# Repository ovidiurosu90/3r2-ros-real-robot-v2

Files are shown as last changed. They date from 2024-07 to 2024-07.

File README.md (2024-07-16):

# [3R2 ROS Real Robot v2](https://github.com/ovidiurosu90/3r2-ros-real-robot-v2)

## Abstract
### Problem
Navigate autonomously without a given map while avoiding obstacles

### Solution
Autonomous Robot Car on ROS

### How
- the whole project is open-source, and can be replicated by interested parties (note it requires a variety of skills like coding, 3d printing, soldering & crimping)
- the robot is able to create a map of an unknown place, then navigate on that map while avoiding obstacles
- SLAM packages on top of ROS are used for navigation

### Notes
- This project was brought to light from my private repository. Some of the resources may be obsolete by now, though feel free to reach out if you need any help
- This project was originally forked from James Bruton's Really Useful Robot (March 2021). His GitHub repository is [here](https://github.com/XRobots/ReallyUsefulRobot "XRobots/ReallyUsefulRobot on GitHub").

## Images

3R2 ROS Real Robot v2 360 rotation

3R2 ROS Real Robot v2 assembly

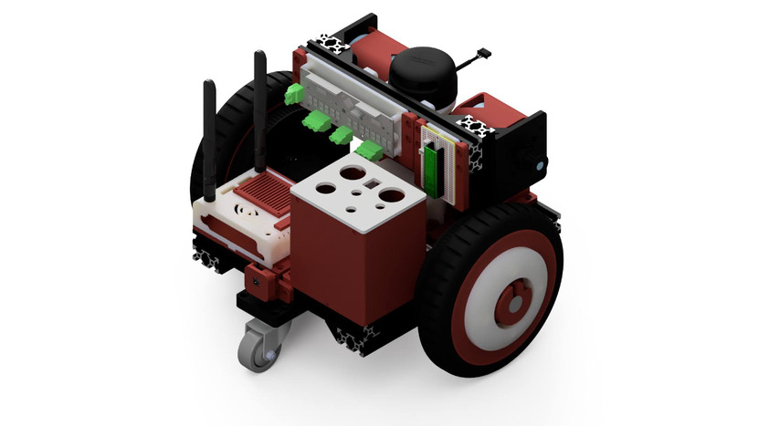
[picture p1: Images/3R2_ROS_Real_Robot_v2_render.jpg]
3R2 ROS Real Robot v2 render


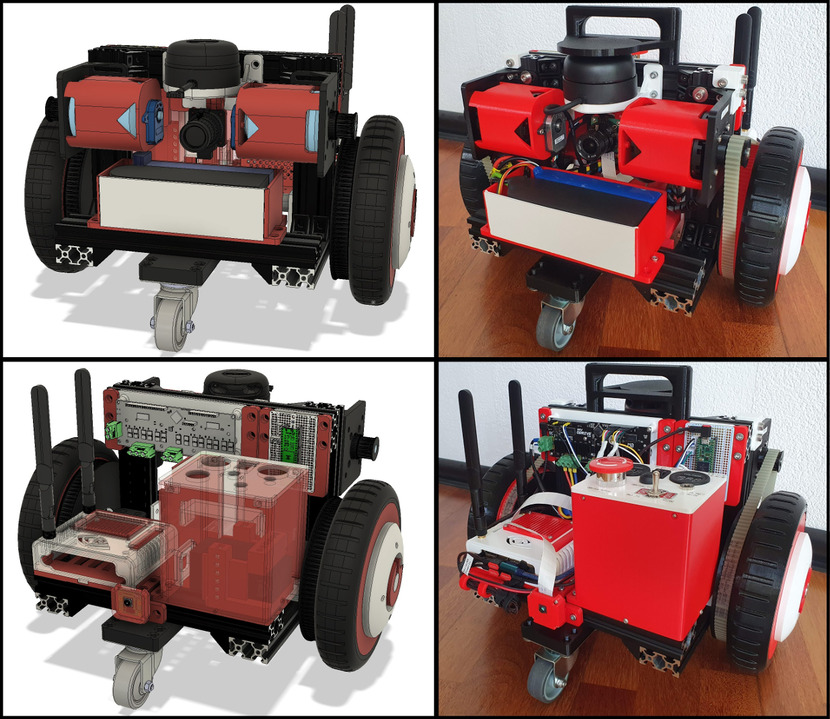
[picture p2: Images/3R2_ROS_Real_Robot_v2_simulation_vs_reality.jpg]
3R2 ROS Real Robot v2 simulation vs reality


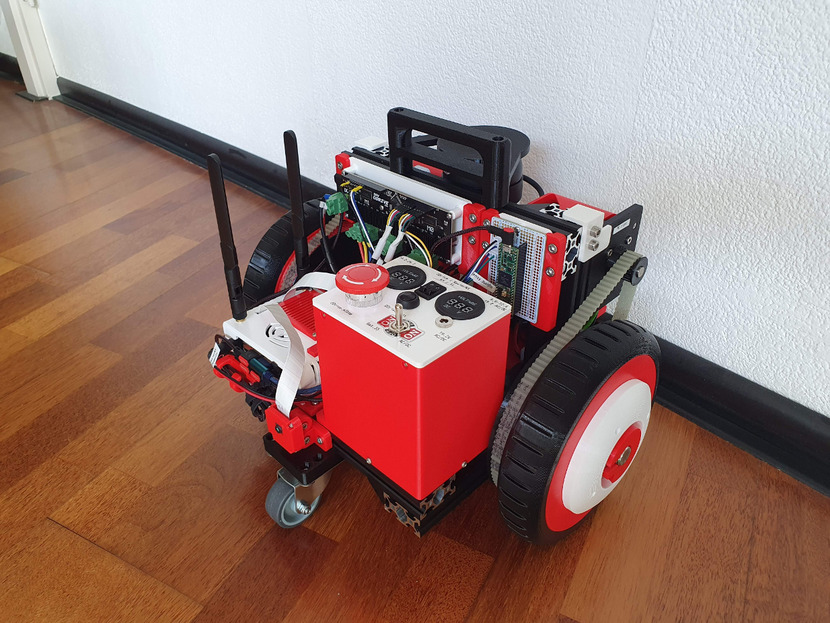
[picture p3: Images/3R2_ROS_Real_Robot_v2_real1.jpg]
3R2 ROS Real Robot v2 real 1


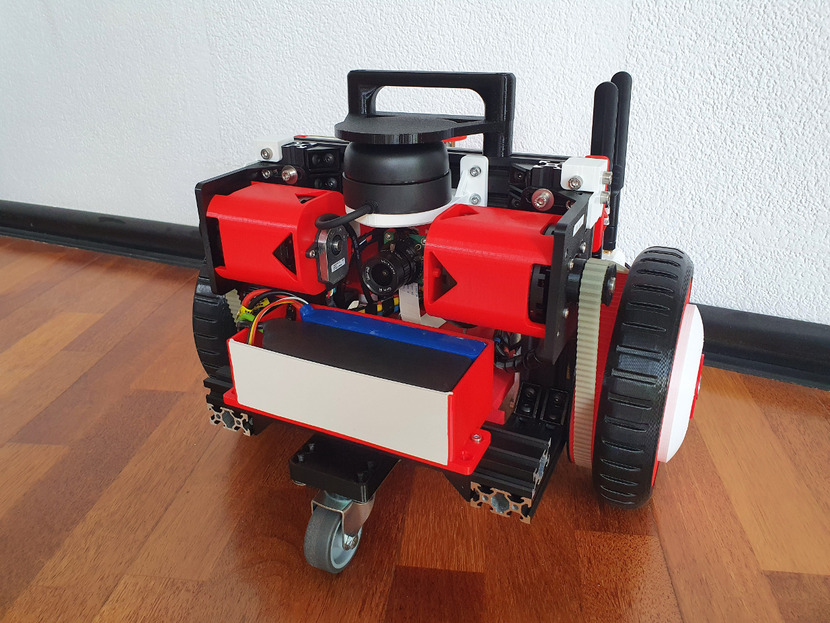
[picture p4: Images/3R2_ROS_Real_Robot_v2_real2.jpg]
3R2 ROS Real Robot v2 real 2


## Getting Started

### Setup 3R2 repository
```bash
mkdir ~/Repositories
cd ~/Repositories/
git clone https://github.com/ovidiurosu90/3r2-ros-real-robot-v2.git
cd 3r2_ros_real_robot_v2/
vim README.md
```

### Install ODrive
```bash
# Install odrivetool: https://docs.odriverobotics.com/#downloading-and-installing-tools
sudo apt-get update
sudo apt-get upgrade
sudo apt install python3 python3-pip
pip3 install matplotlib # optional
pip3 install --upgrade odrive
sudo bash -c "curl https://cdn.odriverobotics.com/files/odrive-udev-rules.rules > /etc/udev/rules.d/91-odrive.rules && udevadm control --reload-rules && udevadm trigger"

vim ~/.bashrc
######
export PATH=$PATH:~/.local/bin
######
source ~/.bashrc
```

### Configure ODrive
```bash
odrivetool
odrv0.erase_configuration() # resets configuration to the factory defaults

odrv0.axis0.controller.config.vel_limit = 16 # default: 2.0
odrv0.axis1.controller.config.vel_limit = 16 # default: 2.0

odrv0.axis0.motor.config.current_lim = 20 # default: 10.0
odrv0.axis1.motor.config.current_lim = 20 # default: 10.0

# Check the calibration current
odrv0.axis0.motor.config.calibration_current # default: 10.0

# Without this setting, I got the ODRIVE_ERROR_DC_BUS_OVER_REGEN_CURRENT error right after the motor stops
odrv0.config.dc_max_negative_current = -8 # default: -0.009999999776482582

# Use encoder index; index = reference point for that encoder to know where to start to count position.
# When the ODrive powers up, the motor will spin until it finds that index
odrv0.axis0.encoder.config.use_index = True # default: False
odrv0.axis1.encoder.config.use_index = True # default: False

odrv0.save_configuration()

# Run full calibration (only once)
odrv0.axis0.requested_state = AXIS_STATE_FULL_CALIBRATION_SEQUENCE
odrv0.axis1.requested_state = AXIS_STATE_FULL_CALIBRATION_SEQUENCE

# Avoid doing the calibration every time the ODrive powers up
odrv0.axis0.encoder.config.pre_calibrated = True # default: False
odrv0.axis1.encoder.config.pre_calibrated = True # default: False

# Look for the index, there's no way around that
# NOTE Make sure there is enough clearance for the motor to move (max 1 turn)
odrv0.axis0.config.startup_encoder_index_search = True # default: False
odrv0.axis1.config.startup_encoder_index_search = True # default: False

# Play the beep sound every time the ODrive powers up
odrv0.axis0.config.startup_motor_calibration = True # default: False
odrv0.axis1.config.startup_motor_calibration = True # default: False

#NOTE You can switch to idle state
# odrv0.axis0.requested_state = AXIS_STATE_IDLE
# odrv0.axis1.requested_state = AXIS_STATE_IDLE

#NOTE You can switch to closed loop state
# odrv0.axis0.requested_state = AXIS_STATE_CLOSED_LOOP_CONTROL
# odrv0.axis1.requested_state = AXIS_STATE_CLOSED_LOOP_CONTROL

#NOTE You can setup the ODrive to enter the closed loop state
# odrv0.axis0.config.startup_closed_loop_control = True # default: False
# odrv0.axis1.config.startup_closed_loop_control = True # default: False

odrv0.save_configuration()
quit
```

### Install PlatformIO
```bash
# Install PlatformIO: https://docs.platformio.org/en/latest//core/installation.html
#NOTE Don't install it in a python virtual environment, as it's causing issues with ROS packages
python3 -m pip install platformio

pio device list

# Setup udev rules for Teensy: https://www.pjrc.com/teensy/00-teensy.rules
sudo vim /etc/udev/rules.d/00-teensy.rules
sudo udevadm control --reload-rules && sudo udevadm trigger
# Unplug Teensy's USB then plug it back
```

### Setup Consistent USB symlinks
```bash
platformio device list
udevadm info -a -n /dev/ttyUSB0 | less
# Copy kernel id for each device (e.g. 1-2.3:1.0)

# JetsonXavierNX
# USB0 | USB2 => 1-2.1:1.0 | 1-2.3:1.0
# USB1 | USB3 => 1-2.2:1.0 | 1-2.4:1.0

sudo vim /etc/udev/rules.d/24-usb.rules
#######################################
SUBSYSTEMS=="usb", KERNELS=="1-2.1:1.0", SYMLINK+="O_ttyUSB0"
SUBSYSTEMS=="usb", KERNELS=="1-2.2:1.0", SYMLINK+="O_ttyUSB1"
SUBSYSTEMS=="usb", KERNELS=="1-2.3:1.0", SYMLINK+="O_ttyUSB2"
SUBSYSTEMS=="usb", KERNELS=="1-2.4:1.0", SYMLINK+="O_ttyUSB3"
#######################################

# USB0 => ODrive
# USB1 => BNO055
# USB2 => RPLidar
# USB3 => Teensy

sudo udevadm control --reload-rules
sudo reboot

# Test that the symlinks are correct
ls -la /dev/O_*
platformio device list
```

### Install ROS

We are using ROS Noetic on Ubuntu 20.04 (dual boot on Desktop) because the XavierNX's OS is based on Ubuntu 20.04 (September 2022)

[Instructions](http://wiki.ros.org/noetic/Installation/Ubuntu)

```bash
lsb_release -a
sudo sh -c 'echo "deb http://packages.ros.org/ros/ubuntu $(lsb_release -sc) main" > /etc/apt/sources.list.d/ros-latest.list'
sudo apt install vim curl
curl -s https://raw.githubusercontent.com/ros/rosdistro/master/ros.asc | sudo apt-key add -
sudo apt update
sudo apt install ros-noetic-desktop-full
apt search ros-noetic
source /opt/ros/noetic/setup.bash
echo "source /opt/ros/noetic/setup.bash" >> ~/.bashrc
source ~/.bashrc
sudo apt install python3-rosdep python3-rosinstall python3-rosinstall-generator python3-wstool build-essential
sudo rosdep init
rosdep update

# vim ~/.ignition/fuel/config.yaml # change url to https://api.ignitionrobotics.org
```

### Setup ROS

[Instructions](http://wiki.ros.org/ROS/Tutorials/catkin/CreateWorkspace)

```bash
mkdir -p ~/catkin_ws/src/
cd ~/catkin_ws/
catkin_make

source devel/setup.bash
echo "source !/catkin_ws/devel/setup.bash" >> ~/.bashrc
source ~/.bashrc

roscd
cd ../src
ln -s ~/Repositories/3r2_ros_real_robot_v2/ROS/geometry2/ .
ln -s ~/Repositories/3r2_ros_real_robot_v2/ROS/jetson_camera/ .
ln -s ~/Repositories/3r2_ros_real_robot_v2/ROS/ros_imu_bno055/ .
ln -s ~/Repositories/3r2_ros_real_robot_v2/ROS/ros_real_robot_v2/ .
ln -s ~/Repositories/3r2_ros_real_robot_v2/ROS/ros_real_robot_v2_simulations/ .
ln -s ~/Repositories/3r2_ros_real_robot_v2/ROS/rosserial/ .
ln -s ~/Repositories/3r2_ros_real_robot_v2/ROS/rplidar_ros/ .

cd ..
rm -rf build/ .catkin_workspace devel/
catkin_make
source ~/.bashrc
rospack profile

sudo ln -s /usr/include/opencv4/opencv2/ /usr/include/opencv

sudo apt-get install ros-noetic-teleop-twist-keyboard ros-noetic-rosbash ros-noetic-xacro ros-noetic-joint-state-publisher-gui ros-noetic-gmapping ros-noetic-slam-gmapping ros-noetic-map-server ros-noetic-navigation ros-noetic-ros-tutorials ros-noetic-compressed-image-transport ros-noetic-camera-info-manager ros-noetic-rviz-imu-plugin ros-noetic-robot-localization ros-noetic-rosserial-arduino

rosdep update
rosdep install --from-paths . --ignore-src

sudo apt install python3-pip
pip3 install pyyaml rospkg pyserial

#NOTE Only for XavierNX
sudo chmod 777 /dev/O_ttyUSB2 # RPLidar
sudo adduser [USERNAME] dialout
sudo reboot
```

### Run ROS
```bash
# Press small pushbutton to initialise the ODrive

# Run the following in different terminals on the SBC (NVIDIA Jetson Xavier NX)

roscore

roslaunch ros_real_robot_v2_bringup robot.launch

# rosrun teleop_twist_keyboard teleop_twist_keyboard.py
rosrun ros_real_robot_v2_teleop ros_real_robot_v2_teleop_key

rostopic echo /tf

rostopic echo /odom
    # twist.twist.linear.x should be similar to speed in teleop
    # twist.twist.angular.x & y could be used for debugging the pos0 and pos1 from ODrive
    #     (NOTE Check the code on the MainControllerTeensy)
```

### Upload the firmware on the Main Controller (Teensy 4.1)
```bash
cd ~/Repositories/3r2_ros_real_robot_v2/Arduino/MainControllerTeensy/
vim src/main.cpp
pio run --target upload
```

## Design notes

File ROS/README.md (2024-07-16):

# **ROS Setup**

## TODO [Tune ROS navigation parameters](https://kaiyuzheng.me/documents/navguide.pdf)

## Simulations

### Simple test in empty world
```bash
roslaunch ros_real_robot_v2_gazebo empty_world.launch
roslaunch ros_real_robot_v2_bringup model.launch

# rosrun teleop_twist_keyboard teleop_twist_keyboard.py
rosrun ros_real_robot_v2_teleop ros_real_robot_v2_teleop_key
```

### Creating a map with gmapping
```bash
roslaunch ros_real_robot_v2_gazebo turtlebot3_house.launch
roslaunch ros_real_robot_v2_slam slam.launch

rosrun ros_real_robot_v2_teleop ros_real_robot_v2_teleop_key

roscd ros_real_robot_v2_navigation/maps/
rosrun map_server map_saver -f turtlebot3_house
```

### Navigating on a known map
```bash
roslaunch ros_real_robot_v2_gazebo turtlebot3_house.launch
roslaunch ros_real_robot_v2_navigation navigation.launch map_file:=$(rospack find ros_real_robot_v2_navigation)/maps/turtlebot3_house.yaml

# Rotate until the number of particles is small and they are under or close to the robot
# After the pose estimate is okay, close this node, otherwise it will conflict with the nevigation stack
rosrun ros_real_robot_v2_teleop ros_real_robot_v2_teleop_key
```

#### Note known error with roswtf

While runing the navigation stack, roswtf shows the following error:

```bash
roswtf

ERROR The following nodes should be connected but aren't:
 * /move_base->/move_base (/move_base/global_costmap/footprint)
 * /move_base->/move_base (/move_base/local_costmap/footprint)
```

You can ignore it as it is being shown while running the navigation stack on turtlebot3 as well.

`rqt_graph` && `rosrun rqt_tf_tree rqt_tf_tree` are showing similar results with turtlebot3 in simulation.

## Real World

### Known IPs
- XavierNX:    192.168.50.108
- Desktop:     192.168.50.136
- Leptop:      192.168.50.198

### Network Test

```bash
# On Ubuntu (0)
export ROS_HOSTNAME=192.168.50.136
export ROS_MASTER_URI=http://192.168.50.136:11311
export ROS_IP=192.168.50.136
roscore

# On XavierNX (0)
export ROS_MASTER_URI=http://192.168.50.136:11311
export ROS_IP=192.168.50.108
rosrun rospy_tutorials listener.py

# On Ubuntu (1)
export ROS_HOSTNAME=192.168.50.136
export ROS_MASTER_URI=http://192.168.50.136:11311
export ROS_IP=192.168.50.136
rosrun rospy_tutorials talker.py

# You should see data being sent between two nodes
```

### Network Setup
```bash
# On Ubuntu (0)
vim ~/.bashrc
#########################
source /opt/ros/noetic/setup.bash
source ~/catkin_ws/devel/setup.bash
export ROS_HOSTNAME=192.168.50.136
export ROS_MASTER_URI=http://192.168.50.136:11311
export ROS_IP=192.168.50.136
#########################
source ~/.bashrc

# On XavierNX (0)
vim ~/.bashrc
#########################
source /opt/ros/noetic/setup.bash
source ~/catkin_ws/devel/setup.bash
export ROS_MASTER_URI=http://192.168.50.136:11311
export ROS_IP=192.168.50.108
#########################
source ~/.bashrc
```

### Building the map
```bash
# On Ubuntu (0)
roscore

# On XavierNX (0)
roslaunch ros_real_robot_v2_bringup robot.launch

# On Ubuntu (1)
roslaunch ros_real_robot_v2_slam slam.launch

# On Ubuntu (2)
rosrun ros_real_robot_v2_teleop ros_real_robot_v2_teleop_key
# Move around until the map is complete

# On Ubuntu (3)
roscd ros_real_robot_v2_navigation/maps/
rosrun map_server map_saver -f apartment1
```

## Navigate the known map
```bash
# On Ubuntu (0)
roscore

# On XavierNX (0)
roslaunch ros_real_robot_v2_bringup robot.launch

# On Ubuntu (1)
roslaunch ros_real_robot_v2_navigation navigation.launch
# roslaunch ros_real_robot_v2_navigation navigation.launch map_file:=/home/[USERNAME]/catkin_ws/src/ros_real_robot_v2/ros_real_robot_v2_navigation/maps/apartment1.yaml

# On Ubuntu (2): Check if everything is fine
cd ~/Desktop/
rosrun tf view_frames && evince frames.pdf
```

# Adafruit BNO055 IMU

## View IMU

```bash
# On Ubuntu (0)
roscore

# On XavierNX (0)
# roslaunch ros_real_robot_v2_bringup imu.launch # IMU operation_mode
# roslaunch ros_real_robot_v2_bringup imu.launch operation_mode:=NDOF_FMC_OFF
roslaunch ros_real_robot_v2_bringup imu.launch operation_mode:=NDOF

# On Ubuntu (1)
roslaunch ros_real_robot_v2_utils view_imu.launch

# On XavierNX (1)
rosservice call /imu/reset_device "{}" # Reset orientation of the axis perpendicular to the ground plane
rosservice call /imu/calibration_status "{}"
```

## Calibration IMU

```bash
# On Ubuntu (0)
roscore

# On XavierNX (0)
roscd ros_imu_bno055/src # this is where the calibration files will be stored
# rm IMU_calibration NDOF_FMC_OFF_calibration
roslaunch ros_imu_bno055 imu_calibration.launch serial_port:=/dev/O_ttyUSB1 operation_mode:=IMU
roslaunch ros_imu_bno055 imu_calibration.launch serial_port:=/dev/O_ttyUSB1 operation_mode:=NDOF_FMC_OFF
roslaunch ros_imu_bno055 imu_calibration.launch serial_port:=/dev/O_ttyUSB1 operation_mode:=NDOF
```

## Sensor Fusion

```bash
# On Ubuntu (0)
roscore

# On XavierNX (0)
roslaunch ros_real_robot_v2_bringup robot.launch

# On Ubuntu (1)
roslaunch ros_real_robot_v2_bringup model.launch
# Add rviz_imu_plugin (Create visualization by display type), select topic /imu/data, enable box

# On Ubuntu (2)
rosrun ros_real_robot_v2_teleop ros_real_robot_v2_teleop_key
```

# Run tests

## cmd_vel_odom_test0 in simulation (Feb 05, 2022)
```bash
roslaunch ros_real_robot_v2_gazebo empty_world.launch
roslaunch ros_real_robot_v2_bringup model.launch
rosrun ros_real_robot_v2_utils cmd_vel_odom_test0.py

# Results (3 tries, ~200 odom msgs): linearError% between(-0.23, 1.55) and angularError% between(1.30, 3.13)
```

## cmd_vel_odom_test0 in the real world (Feb 05, 2022)
```bash
# On Ubuntu (0)
roscore

# On XavierNX (0)
roslaunch ros_real_robot_v2_bringup robot.launch

# On Ubuntu (1)
roslaunch ros_real_robot_v2_bringup model.launch

# On Ubuntu (2)
rosrun ros_real_robot_v2_utils cmd_vel_odom_test0.py

# Results (4 tries, ~360 odom msgs): linearError% between(-9.55, -10.12) and angularError% between(-9.93, -10.23)
```

## cmd_vel_odom_test0 in the real world (Feb 12, 2022)
```bash
# The commands are the same as above

# Results (3 tries, ~200 odom msgs): linearError% between(-0.19, 0.26) and angularError% between(-0.09, 0.11)
# The inconsistency is now fixed.
# The error was that the code was trying to maintain a transfer rate of 100Hz but it wasnâ€™t able to.
# The calculations were implying that, which was wrong. Using the correct cycle time (instead of the inferred one) fixed the issue.
```

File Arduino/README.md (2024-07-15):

# Arduino
Programming the microcontroller was done using [PlatformIO](https://platformio.org/) - Arduino framework.

TODO Before uploading the firmware to the microcrontroller, we have to set a few configuration parameters.

I use a custom made script that bundles a few of the PlatformIO together, though in short, these are the steps to be run to program the microcontroller:
```bash
platformio pkg update
platformio run
platformio run --target upload
platformio device monitor --port /dev/O_ttyUSB0 --baud 115200 | ts [%Y-%m-%d %H:%M:%S] | tee -a MainControllerTeensy.log
```

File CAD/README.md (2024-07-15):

# CAD
I am using Autodesk Fusion 360 as the main CAD software.
In this folder you can find the .f3z file, which contains all the .f3d Fusion 360 3D design files. I chose to upload the f3z file instead of a bundle of STEP files as it holds the complete design and it's way easier to update.

NOTE Install Autodesk Fusion 360, then import everything by following the steps:

1. create a new project by clicking ‘New Project’ in the left toolbar
1. open the new project by double clicking its name
1. upload the .f3d archive from GitHub ([CAD](CAD)) by clicking ‘Upload’ in the left toolbar
1. wait a few minutes, this is uploading multiple designs to your Fusion 360 project
1. open the main assembly (3R2 ROS Real Robot v2 September 2022) by double clicking its name. It should look something like this

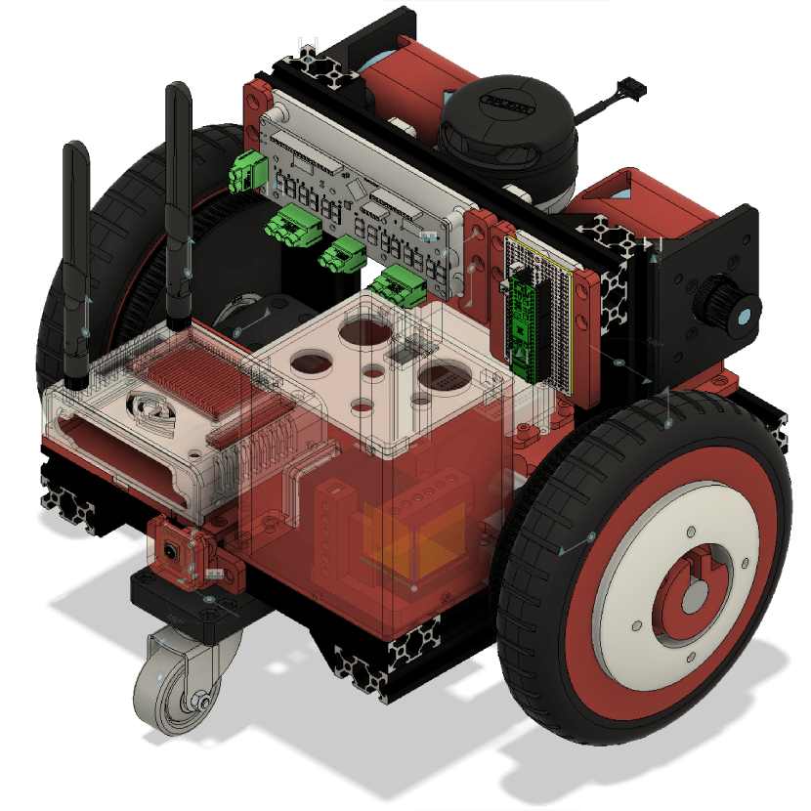
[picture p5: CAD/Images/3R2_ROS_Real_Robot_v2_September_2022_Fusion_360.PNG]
3R2 ROS Real Robot v2 September 2022 in Fusion 360


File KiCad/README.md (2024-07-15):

# KiCad
I am using KiCad 8.0 as the main electronics design software. The project at the moment has no custom PCBs, though you can find an overall connection diagram (between different components) that was designed with this tool.

## TODO Images

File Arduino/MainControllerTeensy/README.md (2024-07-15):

[//]: # (Some of the lines end with 2 spaces. This is the way to specify a line break in markdown)

# Wheel Reduction

ODrive updated their firmware and starting with v0.5.1 **'encounter counts' changed to 'turns'**. For more info check ODrive's [Migration Guide](https://docs.odriverobotics.com/migration).

In the original release from James Bruton (commit on Nov 3, 2020), the encoder units were encoder counts. Now we use turns.

## Hardware

We use ODrive's [CUI AMT102](https://eu.odriverobotics.com/shop/cui-amt-102) capacitive encoders, which have 8192 counts per resolution.

The motor pulleys have 15 teeth. The wheel pulleys have 96 teeth.  
96/15 = 6.4 => 15:96 reduction == **6.4:1** reduction

The wheels have 200mm in diameter. Circumference C = 2 * PI * radius.  
C = 2 * 3.141592 * 100 => **628.318530** mm calculated circumference (approximated by James at 628.32; 633 in reality).

The distance between wheels is **346** mm in the 3d model (353 mm in reality).

## Driving Forward

1 revolution of the wheel means 628.318530 mm (approximated by James at 628.32) travelled.

The motor needs to turn 6.4 times to make a full revolution (because of the 6.4:1 reduction).

1 wheel revolution = 6.4 motor turns = 6.4 * 8192 encoder counts = 52428.8 encoder counts (approximated by James at 52428).

1 wheel revolution = 628.318530 mm => for each travelled mm we have 52428.8 / 628.318530 encoder counts.  
52428.8 / 628.318530 = 83.443026 encoder counts per mm (approximated by James to 83.44, value in his code)

6.4 motor turns / 628.318530 mm = **0.010185** turns per mm (value in my code based on 3d model measurements)

### Calculate the number of encoder counts / turns we need in order to travel at 1 meter per second

1 revolution ... 628.318530 mm  
x revolution ... 1000 mm (1m)  
x = 1 * 1000 / 628.318530 = 1.591549 revolutions per m (approximated by James to 1.592)

1.591549 revolutions per m * 52428.8 encoder counts = 83443.004211 encoder counts per m  
1.591549 revolutions per m * 6.4 turns = 10.185913 turns per m

each meter / sec = 83443.004211 encoder counts (approximated by James to 83466, value in his code)  
each meter / sec = **10.185916** turns (value in my code based on 3d model measurements)

## Turning

360 degrees = 2 * PI radians  
180 degress = PI radians

### Distance each wheel has to travel in order to turn 180 degrees

346 mm (distance between wheels) * PI / 2 (number of wheels)  
= 346 * 3.141592 / 2 = 543.495416 mm (approximated by James to 565.48 mm)

1 revolution ... 628.318530 mm  
x revolution ... 543.495416 mm  
x = 1 * 543.495416 / 628.318530 = 0.864999 revolutions

0.864999 revolutions * 6.4 motor turns = 5.535998 motor turns (NOTE James has 5.78 here)  
5.535998 * 8192 = 45350.902616 encoder counts (approximated by James to 47411)

1 radian = 45350.902616 / PI = 14435.643653 encoder counts (approximated by James to 15091, value in his code)  
1 radian = 5.535998 / PI = **1.762163** turns (value in my code based on 3d model measurements)

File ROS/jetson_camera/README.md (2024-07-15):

# Jetson CSI camera node(let)

Forked from [sfalexrog' jetson_camera](https://github.com/sfalexrog/jetson_camera). I've changed the OpenCV version from 3 to 4, I've added sensor_id and camera_name.

The node(let) is based on the [JetsonHacks' Jetson Nano CSI repository](https://github.com/JetsonHacksNano/CSI-Camera). As such, it only supports Raspberry Pi v2 cameras (and others that are supported by Jetson Nano). Additionally, it requires OpenCV with GStreamer support (see [JetsonHacks' OpenCV build scripts](https://github.com/JetsonHacksNano/buildOpenCV) to build one).

## Parameters

* `cap_width`, `cap_height` (*int*, default: 1280, 720) - Width and height of the captured image. **These parameters only affect the capturing mode!** Be sure to set them to one of the supported modes for your camera (Raspberry Pi camera v2 supports 3280x2464@21fps, 3280x1848@28fps, 1920x1080@30fps, 1280x720@60fps).
* `width`, `height` (*int*, default: 640, 480) - Width and height of the output image.
* `fps` (*int*, default: 60) - Desired framerate/publish rate [Hz].
* `flip_method` (*int*, default 0) - Image rotation/flipping. `0` for no rotation, see detailed description [at JetsonHacks](https://github.com/JetsonHacksNano/CSI-Camera#gstreamer-parameter).
* `frame_id` (*string*, default: "main_camera_optical")- Camera frame name.
* `capture_delay` (*double*, default: 0) - Additional time (in seconds) that is **substracted** from the timestamp. Allows to compensate for capture delays.
* `topic_name` (*string*, default: "image_raw") - Image topic name.
* `camera_info_url` (*string*, default: "") - URL pointing to the camera info yaml file.

## Nodelet

The node is meant to run as a nodelet (`jetson_camera/JetsonCameraNodelet`). In fact, the node is basically a standalone simplified nodelet manager.

## Miscellaneous stuff

### Red tint on camera image

The image captured by this node may have a red tint that is more pronounced near the edges. This can be fixed to a degree by using an ISP camera override.

An ISP override file for an Arducam imx219 board (`camera_overrides.isp`) is placed in this repository in the `extra` folder. Place it in the `/var/nvidia/nvcam/settings` on your Jetson Nano, set its permissions to `664` and its owner:group to `root:root`.

Note that, [according to RidgeRunner](https://developer.ridgerun.com/wiki/index.php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), only ODMs have access to the required tools for ISP calibration files.

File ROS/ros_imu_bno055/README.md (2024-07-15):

# ros_imu_bno055

Forked from [RoboticArts'  ros_imu_bno055](https://github.com/RoboticArts/ros_imu_bno055). I didn't make any changes.

**Author**: Robert Vasquez Zavaleta

*Robotic Arts, All Rights Reserved 2020*

Software License Agreement (BSD License)

**Description**: ROS driver for the BNO055 IMU using serial communication. Also it allows the configuration and calibration of the IMU

## Overview

BNO055 IMU is a Bosh sensor that  integrates an accelerometer, a gyroscope and a magnetometer in one package. Unlike other IMUs, the BNO055 is able to directly offer orientation in space. This is thanks to the different sensory fusion algorithms implemented on the chip. In this way, it is not necessary to perform additional calculations. Also, it is capable of using I2C or UART communication.

**This repository offers a ROS package** and an API written in python to **communicate with the IMU BNO055 using UART** communication through a USB Serial Converter. In addition, all the necessary functionalities have been **implemented** to correctly use the **sensor calibration**. On the other hand, thanks to the API it **is possible to set** various **configuration parameters** of the IMU.

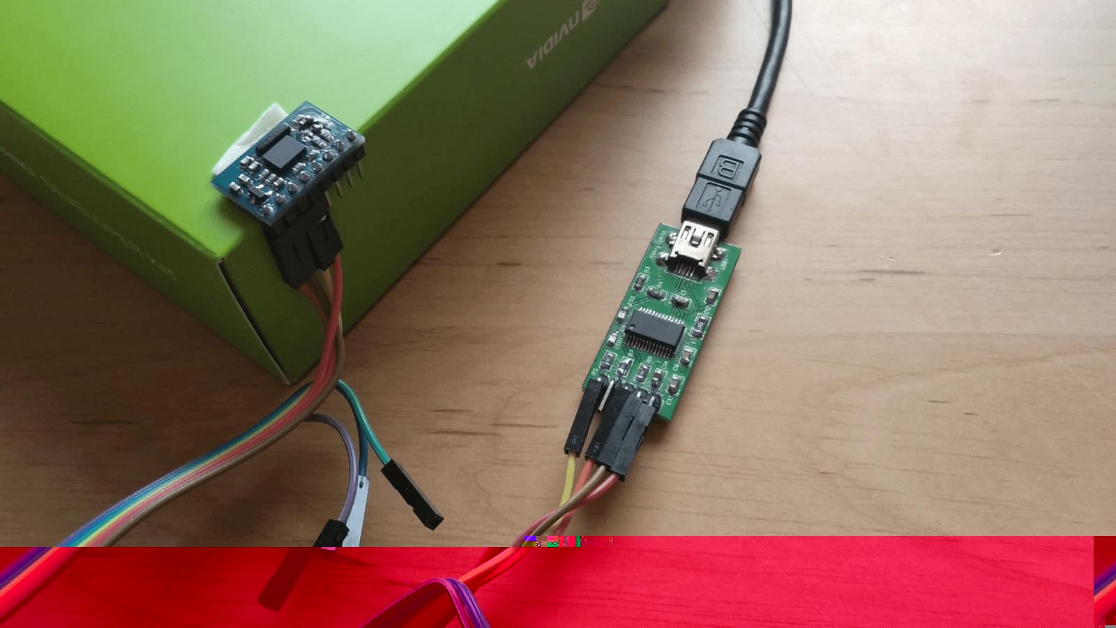
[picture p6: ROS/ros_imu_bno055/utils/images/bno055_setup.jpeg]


## 1. Requisites

* Ubuntu with ROS Kinetic or Melodic
* Python 3
* Bosch IMU BNO055
* USB Serial Converter

## 2. Hardware setup

There are different boards that incorporate the BNO055 IMU. The cheapest one is from Aliexpress. This board has two solder bridges called PS0 and PS1 used to select the type of communication. 

On the other hand, on this board the solder bridges are inverted. This means that its state is 1 if the bridge is not soldered. If the bridge is soldered the state is 0. The table on the left, obtained from the BNO055 datasheet, shows the communication modes based on PS0 and PS1

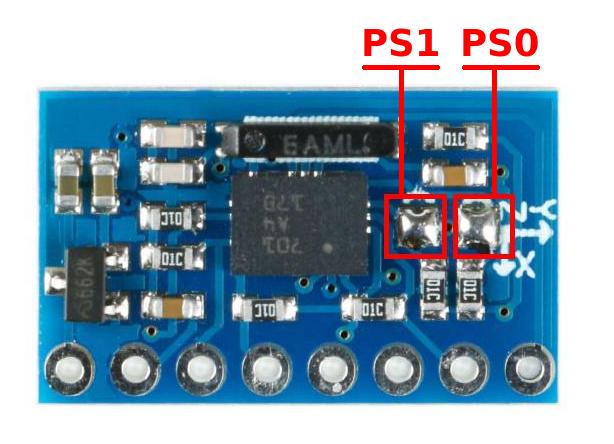
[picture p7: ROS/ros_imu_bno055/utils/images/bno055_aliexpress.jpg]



**To use the IMU in this package**, it must be configured in **UART mode** to be able to communicate with the serial to USB converter. Therefore PS0 = 0 and PS1 = 1. Remember that on this board the solder bridges are inverted, so the PS1 bridge must be unsolder.

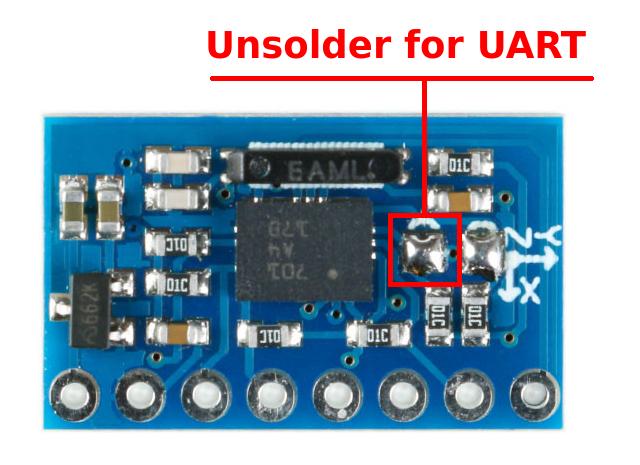
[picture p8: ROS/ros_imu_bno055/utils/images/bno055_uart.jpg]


Finally, connect the IMU to the serial to USB converter. The Rx and Tx cables are crossed. The power of the BNO055 module is 5V



If you are using a different board, for example the Adafruit board or a different Chinese board, use [this link](https://gr33nonline.wordpress.com/2019/04/19/dont-get-the-wrong-bno055/)

## 3. Dependences

ros_imu_bno055 package depends on the following python/ros packages:

* pyserial
* rviz_imu_plugin

## 4. Installation

Install ros_imu_bno055 package

```
$ cd ~/catkin_ws/src
$ git clone https://github.com/RoboticArts/ros_imu_bno055.git
```

It is important to compile the package so that the libraries are added correctly

```
$ cd ~/catkin_ws
$ catkin_make --only-pkg-with-deps ros_imu_bno055
$ source devel/setup.bash
```

By default the standard ROS installation does not include any plugin to display the orientation of the IMUs in rviz. Therefore, you will need to install the **Imu plugin**. If you does not need to see the IMU in rviz you can skip this step.

Kinetic:
```
$ sudo apt-get install ros-kinetic-rviz-imu-plugin
```
Melodic:
```
$ sudo apt-get install ros-melodic-rviz-imu-plugin
```

Finally pyserial must be installed if it is not on the computer. 

```
$ pip install pyserial
```

(Optional) If you are using a Serial to USB converter with the **original FTDI chip** you can install the udev rule to identify the device as ```ttyUSB_IMU```

```
$ roscd ros_imu_bno055
$ sudo cp utils/99-bno055.rules /etc/udev/rules.
$ sudo udevadm control --reload-rules && sudo udevadm trigger
```

## 5. View IMU

1. Make sure to connect the IMU well to the computer. Check the Hardware Setup section for more information

2. In a terminal, launch the following command to display the IMU in RVIZ

```
$ roslaunch ros_imu_bno055 view_imu.launch
```

3. Move the IMU to view its orientation in RVIZ.



## 6. BNO055 ROS driver

1. Use the command below to start the driver in ROS. This launch file is the same as the previous one but neither the tf nor rviz is published

```
$ roslaunch ros_imu_bno055 imu.launch serial_port:=/dev/ttyUSB0
```

2. This driver allows to configure various parameters of the IMU. The following table describes each parameter

| Argument | Default value | Description |
| --- | --- | --- |
| serial_port | /dev/ttyUSB0 | USB port where the IMU is connected (using a USB Serial Converter ) |
| frame_id | imu_link | Name of the link that the tf will use |
| operation_mode | IMU |  Type of sensory fusion used by the IMU. The next section will explain each mode in detail. |
| oscillator | INTERNAL | Use internal or external oscillator. Set EXTERNAL if you BNO055 board has a external oscillator to get more accurate clock vary for lower sensitivity error (this does not improve drift).
| reset_orientation | true | Resets the IMU to resets the orientation of the axis that is located perpendicular to the ground plane. This is important since the movements are relative to the first position the IMU had when it was turned on or reset. Set it to True to reset the position every time the driver is launched|
| frequency | 50 | Frequency of reading the IMU and publication in ROS. The maximum frequency reached by the IMU is 50 Hz |
| use_magnetometer | false | Enables topic imu/magnetometer |
| use_temperature | false | Enables topic imu/temperature |

3. The IMU BNO055 implements a sensory fusion algorithm based on the accelerometer, gyroscope and magnetometer to obtain orientation. These sensory fusion modes are:

| Operation mode | Description |
| --- | --- |
| IMU | The relative orientation of the BNO055 in space is calculated from the accelerometer and gyroscope data. |
| COMPASS | This mode is intended to measure the magnetic earth field and calculate the geographic direction. The heading  can only be calculated when considering gravity and magnetic field at the same time  |
| M4G | Similar to the IMU mode, but instead of using the gyroscope signal to detect rotation, the changing orientation of the magnetometer in the magnetic field is used. |
| NDOF_FMC_OFF | This fusion mode is same as NDOF mode, but with the Fast Magnetometer Calibration turned ‘OFF’.  |
| NDOF | The absolute orientation data is calculated from accelerometer, gyroscope and the magnetometer.  In this mode the Fast Magnetometer calibration is  turned  ON  and  thereby  resulting  in  quick  calibration  of  the  magnetometer |

4. When selecting an operating mode, the sensors involved and the resulting type of orientation must be taken into account. The table below shows the possible combinations.

**Note: Sensors not used in one mode of operation will turn off.** For example, if the IMU mode is selected, the magnetometer will not work and therefore its value cannot be published in ROS. Also keep in mind that its orientation will be relative.

| Operation mode | Accelerometer | Gyroscope | Magnetometer | Orientation |
| --- | :---: | :---: | :---: | :---: |
| IMU | X | X |  | Relative |
| COMPASS | X |  | X | Absolute |
| M4G | X |  | X | Relative |
| NDOF_FMC_OFF | X | X | X | Absolute |
| NDOF | X | X | X | Absolute |

**5. Reset device service**

When IMU is reset it is possible to reset the orientation of the IMU while the driver is running. **Only the orientation of the axis that is perpendicular to the ground plane will be reset**. To do this, call the service below. After calling the service the IMU will be reset and therefore the initial orientation will be the orientation that it has at that moment.

```
$ rosservice call /imu/reset_device "{}"
```

**6. Calibration status service**

Returns the current state of the calibration. This service should not be called constantly since it stops the publication of the IMU:

```
$ rosservice call /imu/calibration_status "{}"
```

**7. Calibration load**

Every time the driver is launched automatically it will look for the calibration file called ```calibration```. If found, it will load the calibration into the IMU. If not found it will not load it and the IMU will use the internal factory calibration. This file is in the following path:

```
$ roscd ros_imu_bno055/src
```

The file ```calibration``` is a binary file generated by the ```imu_calibration``` node. See the next section to find out how to use that node.

**Every time the IMU is turned on or reset, the calibration must be loaded since the IMU does not have an EEPROM or flash memory.** This driver takes care of it.

8. If you are going to implement it in a launch file:

```
    <include file="$(find imu_ros_bno055)/launch/imu.launch">

        <arg name = "serial_port" value="/dev/ttyUSB0" />
        <arg name = "frame_id" value="imu_link" />
        <arg name = "operation_mode" value="IMU"/>
        <arg name = "oscillator" value="INTERNAL" />
        <arg name = "reset_orientation" value="true" />
        <arg name = "frequency" value="50" /> 
        <arg name = "use_magnetometer" value="false" />
        <arg name = "use_temperature" value="false" /> 

    <launch>
```

9. If you are going to throw it in the terminal:

```
roslaunch ros_imu_bno055 imu.launch serial_port:=/dev/ttyUSB0 operation_mode:=IMU
```

## 7. IMU calibration

BNO055 IMU has an internal factory calibration, however, it is highly recommended to calibrate it. The node ```imu_calibration``` generates a calibration file for the accelerometer, gyroscope, and magnetometer. The generated file will be used by the bno055 ros driver to load it into the IMU. Remember that BNO055 does not have an EEPROM or flash memory to store the calibration so every time the IMU is turned on or reset, the calibration has to be loaded.

**The type of calibration obtained** will **depend on the operating mode** of the IMU (see table in section 6.3). This means that if the IMU will work in NDOF_FMC_OFF mode then the calibration has to be done in that same mode.

To launch the calibration, in this case operation mode will be ```NDOF_FMC_OFF```:

```
roslaunch ros_imu_bno055 imu_calibration.launch serial_port:=/dev/ttyUSB0 operation_mode:=NDOF_FMC_OFF
```

The status of the three sensors will immediately appear on the terminal. Value 0 means there is no calibration, value 3 means full calibration. The parameter ```system```  indicates the current status of the three sensors. A value of 0 indicates that there is no calibration. A value of 3 indicates that the IMU has completed the calibration



* **To calibrate the magnetometer:** Make  some random movements  (for  example:  writing  the  number  ‘8’  on air) until  the magnetometer indicates fully calibrated

* **To calibrate the gyroscope:** Place the device in a single stable position for a period of few seconds to allow the gyroscopeto calibrate

* **To calibrate the accelerometer:** Place the device in 6 different stable positions for a period of few seconds to allow the accelerometer to calibrate. **Make sure that there is slow movement between 2 stable positions**. Make sure that the device is lying at least once perpendicular to the x, y and z axis.

When the IMU is fully calibrated the node will finish and the calibration file will be automatically generated in ``` ros_imu_bno055/src ``` which will be used by bno055 ros driver to load calibration data into the IMU. 

The name of the calibration file will be ```OPERATION_MODE_calibration``` In this example it will be called ```NDOF_FMC_OFF_calibration```



Finally, when calibrating an operation mode, the involved sensors must be taken into account (see table in section 6.4). This means that when calibrating in IMU mode, it will only be done for the accelerometer and gyroscope



For more information about how calibrate BNO055:

(http://www.youtube.com/watch?v=Bw0WuAyGsnY "cal")

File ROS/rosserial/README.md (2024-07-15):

# rosserial

Forked from [ros-drivers' rosserial](https://github.com/ros-drivers/rosserial). I've fixed import Queue in SerialClient.



Please see [rosserial on the ROS wiki](http://wiki.ros.org/rosserial) to get started.

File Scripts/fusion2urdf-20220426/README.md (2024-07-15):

# My fusion2urdf

NOTE I forked this script from [https://github.com/syuntoku14/fusion2urdf](https://github.com/syuntoku14/fusion2urdf) on June 12th, 2022.

## Setup Windows Environment for Fusion 360 Scripts

1. Download and install [Python for Windows](https://www.python.org/downloads/windows/)

2. Download and install [Git for Windows](https://gitforwindows.org/)

3. Clone repository in Git Bash

```bash
mkdir ~/Repositories/
cd ~/Repositories/
git clone https://github.com/ovidiurosu90/3r2-ros-real-robot-v2.git
```

4. Create symlink in Command Prompt (as administrator)

```bash
cd %appdata%/Autodesk/"Autodesk Fusion 360"/API/Scripts/
mklink /D URDF_Exporter [PATH]\3r2-ros-real-robot-v2\Scripts\fusion2urdf-20220426\URDF_Exporter\
```

5. Run Script in Fusion 360

- open ros_real_robot_v2 Design

- go to UTILITIES -> ADD-INS -> Scripts and Add-Ins...

- select URDF_Exporter then click Edit => it will install VS Code automatically

- after installation, try again, this time it should open VS Code

- you can debug the URDF_Exporter from VS Code; debug logs are there as well

## Setup Ubuntu Environment for testing the URDF

```bash
sudo apt install ros-melodic-joint-state-publisher-gui

cd ~/catkin_ws/src/
rm ros_real_robot_v2_description
ln -s /mnt/share/data/2R2\ ROS\ Real\ Robot\ v2/URDF/ros_real_robot_v2_20220913_V5/ros_real_robot_v2_description/ .

cd ..
rm -rf build/ .catkin_workspace devel/
catkin_make
source ~/.bashrc
rospack profile
```

### Post-processing
```bash
roscd ros_real_robot_v2_description/urdf/
# vim plugins.gazebo.xacro

sed -i 's/\[TOFILL_differential_drive_controller_leftJoint\]/wheel_left__base_link/g' plugins.gazebo.xacro
sed -i 's/\[TOFILL_differential_drive_controller_rightJoint\]/wheel_right__base_link/g' plugins.gazebo.xacro
sed -i 's/\[TOFILL_differential_drive_controller_wheelSeparation\]/0.346/g' plugins.gazebo.xacro
sed -i 's/\[TOFILL_differential_drive_controller_wheelDiameter\]/0.20/g' plugins.gazebo.xacro
sed -i 's/\[TOFILL_differential_drive_controller_wheelAcceleration\]/1.0/g' plugins.gazebo.xacro
sed -i 's/\[TOFILL_differential_drive_controller_wheelTorque\]/20/g' plugins.gazebo.xacro

sed -i 's/\[TOFILL_base_scan_reference\]/base_scan/g' plugins.gazebo.xacro
sed -i 's/\[TOFILL_camera_front_reference\]/camera_front_lens/g' plugins.gazebo.xacro
sed -i 's/\[TOFILL_camera_rear_reference\]/camera_rear_lens/g' plugins.gazebo.xacro
sed -i 's/\[TOFILL_imu_link_reference\]/imu_link/g' plugins.gazebo.xacro

###########################################

sed -i 's/wheel_1/wheel_left/g' ros_real_robot_v2.urdf.xacro ../rviz/display.rviz materials.gazebo.xacro physics.gazebo.xacro
sed -i 's/wheel_2/wheel_right/g' ros_real_robot_v2.urdf.xacro ../rviz/display.rviz materials.gazebo.xacro physics.gazebo.xacro
sed -i 's/caster_1/caster_front/g' ros_real_robot_v2.urdf.xacro ../rviz/display.rviz materials.gazebo.xacro physics.gazebo.xacro
sed -i 's/caster_2/caster_rear/g' ros_real_robot_v2.urdf.xacro ../rviz/display.rviz materials.gazebo.xacro physics.gazebo.xacro

sed -i 's/rplidar_1/rplidar/g' ros_real_robot_v2.urdf.xacro ../rviz/display.rviz materials.gazebo.xacro physics.gazebo.xacro
sed -i 's/base_scan_1/base_scan/g' ros_real_robot_v2.urdf.xacro ../rviz/display.rviz materials.gazebo.xacro physics.gazebo.xacro
sed -i 's/camera_front_1/camera_front/g' ros_real_robot_v2.urdf.xacro ../rviz/display.rviz materials.gazebo.xacro physics.gazebo.xacro
sed -i 's/camera_front_lens_1/camera_front_lens/g' ros_real_robot_v2.urdf.xacro ../rviz/display.rviz materials.gazebo.xacro physics.gazebo.xacro
sed -i 's/camera_rear_1/camera_rear/g' ros_real_robot_v2.urdf.xacro ../rviz/display.rviz materials.gazebo.xacro physics.gazebo.xacro
sed -i 's/camera_rear_lens_1/camera_rear_lens/g' ros_real_robot_v2.urdf.xacro ../rviz/display.rviz materials.gazebo.xacro physics.gazebo.xacro
sed -i 's/bno055_1/bno055/g' ros_real_robot_v2.urdf.xacro ../rviz/display.rviz materials.gazebo.xacro physics.gazebo.xacro
sed -i 's/imu_link_1/imu_link/g' ros_real_robot_v2.urdf.xacro ../rviz/display.rviz materials.gazebo.xacro physics.gazebo.xacro

#############################

roscd ros_real_robot_v2_description/meshes/
# ls -la

mv base_scan_1.stl base_scan.stl
mv bno055_1.stl bno055.stl
mv camera_front_1.stl camera_front.stl
mv camera_rear_1.stl camera_rear.stl
mv caster_1.stl caster_front.stl
mv caster_2.stl caster_rear.stl
mv rplidar_1.stl rplidar.stl
mv wheel_1.stl wheel_left.stl
mv wheel_2.stl wheel_right.stl

ls -la
```

### Simulations

```bash
roslaunch ros_real_robot_v2_description display.launch
roslaunch ros_real_robot_v2_description gazebo.launch

# rosrun teleop_twist_keyboard teleop_twist_keyboard.py
rosrun ros_real_robot_v2_teleop ros_real_robot_v2_teleop_key
```

### Update repository

```bash
roscd ros_real_robot_v2_description/
cp -r * ~/Repositories/3r2_ros_real_robot_v2/ROS/ros_real_robot_v2/ros_real_robot_v2_description/
cd ..
rm ros_real_robot_v2_description
rm ros_real_robot

ln -s ~/Repositories/3r2_ros_real_robot_v2/ROS/ros_real_robot_v2/ .

cd ..
rm -rf build/ .catkin_workspace devel/
catkin_make
source ~/.bashrc
rospack profile

# Test again using the commands from 'Simulations'
```

## Images

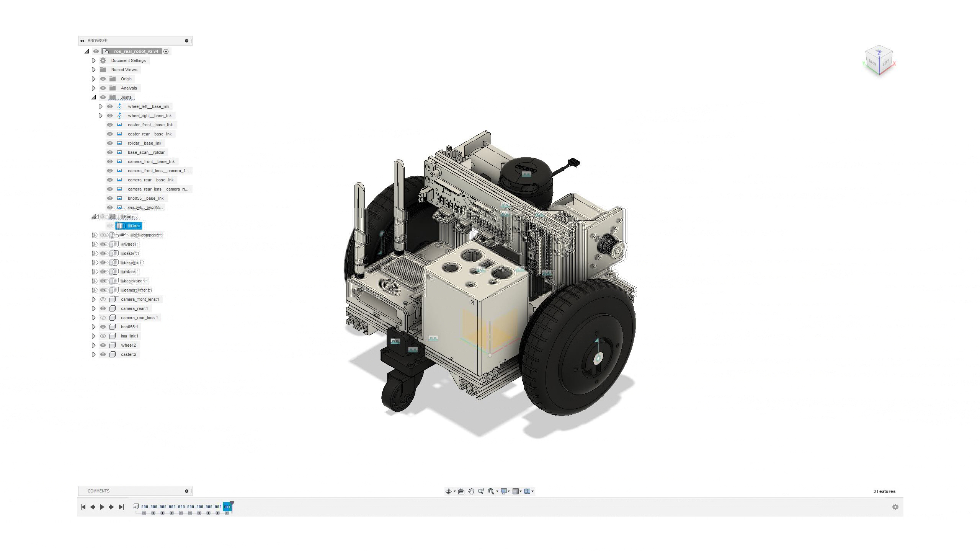
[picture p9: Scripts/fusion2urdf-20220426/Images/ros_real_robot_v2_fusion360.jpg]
ros_real_robot_v2 in Fusion 360


Display Robot in RVIZ

Display Joints in RVIZ

Display Robot in Gazebo

Display Laser Scan in Gazebo

Display Contacts in Gazebo

---

# fusion2urdf - Original

I have stopped developing this repo, but any contributions are welcome.
This repo only supports Gazebo, if you are using pybullet, see: https://github.com/yanshil/Fusion2PyBullet.

## Updated!!!
* 2021/01/09: Fix xyz calculation. 
  * If you see that your components move arround the map center in rviz try this update 
  * More Infos see: https://forums.autodesk.com/t5/fusion-360-api-and-scripts/difference-of-geometryororiginone-and-geometryororiginonetwo/m-p/9837767

* 2020/11/10: README fix
  * MacOS Installation command fixed in README
  * Date format unified in README to yyyy/dd/mm
  * Shifted Installation Upwards for better User Experience and easier to find
* 2020/01/04: Multiple updates:
  * no longer a need to run a bash script to convert stls
  * some cleanup around joint and transmission generation
  * defines a sample material tag instead of defining a material in each link
  * fusion2urdf now generates a self-contained ROS {robot_name}_description package
  * now launched by roslaunch {robot_name}_description display.launch
  * changed fusion2urdf output from urdf to xacro for more flexibility
  * separate out material, transmissions, gazebo elements to separate files
* 2018/20/10: Fixed functions to generate launch files
* 2018/25/09: Supports joint types "Rigid", "Slider" & Supports the joints' limit(for "Revolute" and "Slider"). 
* 2018/19/09: Fixed the bugs about the center of the mass and the inertia.

## Installation

Run the following command in your shell.

##### Windows (In PowerShell)

```powershell
cd <path to fusion2urdf>
Copy-Item ".\URDF_Exporter\" -Destination "${env:APPDATA}\Autodesk\Autodesk Fusion 360\API\Scripts\" -Recurse
```

##### macOS (In bash or zsh)

```bash
cd <path to fusion2urdf>
cp -r ./URDF_Exporter "$HOME/Library/Application Support/Autodesk/Autodesk Fusion 360/API/Scripts/"
```

## What is this script?
This is a fusion 360 script to export urdf from fusion 360 directly.

This exports:
* .urdf file of your model
* .launch and .yaml files to simulate your robot on gazebo
* .stl files of your model

### Sample 

The following test model doesn't stand upright because the z axis is not upright in default fusion 360.
Make sure z axis is upright in your fusion 360 model if you want. 

#### original model
industrial_robot

#### Gazebo simulation of exported .urdf and .launch
* center of mass
center_of_mass

* collision
collision

* inertia
inertia

## Before using this script

Before using this script, make sure that your model has all the "links" as components. You have to define the links by creating corresiponding components. For example, this model(https://grabcad.com/library/spotmini-robot-1) is not supported unless you define the "base_link". 

In addition to that, you should be careful when define your joints. The **parent links** should be set as **Component2** when you define the joint, not as Component1. For example, if you define the "base_link" as Component1 when you define the joints, an error saying "KeyError: base_link__1" will show up.

spot_mini

Also, make sure components of your model has only bodies. **Nested components are not supported**.
For example, this works:

only_bodies

but this doesn't work since the "face (3):1" component contains other components. A component must contain only bodies:

nest_components

Sometimes this script exports abnormal urdf without any error messages. In that case, the joints should have problems. Redefine the joints and run again.

In addition to that, make sure that this script currently supports only "Rigid", "Slider" and "Revolute".

## Complex Kinematic Loops and Spherical joints (may be fixed later):

DO NOT use Fusion 360's inbuilt joint editor dialouge for positioning joints

For example, [@rohit-kumar-j](https://github.com/rohit-kumar-j) had this complicated robot to assemble. There are over.. some 50 joints in all, including some forming loops within the structure like a [4-bar mechanism](https://www.youtube.com/watch?v=eYOt6SEKHFs&ab_channel=YuhangHu), also called **kinematic loops**.



As you can see below, when fusion initailly forms joints, it might not align where you want it to align to. In the image below, the cylinder's cap side doesn't exaclty coincide with the position of the pin where it needs to be join. The red arrow shows the mismatch in initial joint positioning by fusion.



If you were to manually drag the parts and align them as shown below, it would cause cascading problems with the visual and collision properties of certain links. 

Capture

Below you can see one of the cylinders is mismatched as compared to the others (red and grey colors are cylinders) 
(The below urdf is visualized in pybullet)



See Also: Similar to this issue, but only for a few axes [here](https://github.com/yanshil/Fusion2PyBullet/issues/6) (turns out there was a fusion API change back then, and the exporter wasn't yet updated [See this commit](https://github.com/syuntoku14/fusion2urdf/commit/8786e6318cdcaaf32070148451a27ab6e4f6697d), but it now is)

**The fix for this is to leave Fusion's joint controls unedited and form joints for the robot joints (See below)**

A similar issue with another set of joints at the ankle was fixed by following the above fromat. [Here is the video](https://www.youtube.com/watch?v=0hfkm7vv5o8&ab_channel=JRohit)

For spherical joints, it is better to keep them revolute and define the joints as spherical, later in the generated URDF(provided the urdf parser in your visualizer/physics engine(gazebo,webots,pybullet,mujoco,etc) supports spherical joints, in pybullet it does).
The ankle joint below has 4 spherical joints and only two of them were defined as revolute while exporting from fusion 360. The other 2 spherical joints were created in pybullet using pybullet's inbuilt functions for creating kinematic loops.(see the gif below)

youtube-video-gif

## In some cases, before export Turn off "Capture design history"

For preplanning the component placement when working/assembling your own robot. It is recomended to have separate names for components and save individual components in a separate folder, create a back up and, break link with the original. This folder can be later deleted after genearating the urdf. See [Issue #51](https://github.com/syuntoku14/fusion2urdf/issues/51) for problem with "copy-paste" vs "copy-paste new".

## How to use

As an example, I'll export a urdf file from this cool fusion360 robot-arm model(https://grabcad.com/library/industrial-robot-10).
This was created by [sanket patil](https://grabcad.com/sanket.patil-16)

### Install in Shell 

Run the [installation command](#installation) in your shell.

### Run in Fusion 360

Click ADD-INS in fusion 360, then choose ****fusion2urdf****. 

**This script will change your model. So before running it, copy your model to backup.**

copy

Run the script and wait a few seconds(or a few minutes). Then a folder dialog will show up. Choose where you want to save the urdf (A folder "Desktop/test" is chosen in this example").
Maybe some error will occur when you run the script. Fix them according to the instruction. In this case, something wrong with joint "Rev 7". Probably it can be solved by just redefining the joint.

error

**You must define the base component**. Rename the base component as "base_link". 

cautions

In the above image, base_link is grounded. Right-click it and click "Unground". 

Now you can run the script. Let's run the script. Choose the folder to save and wait for a few seconds. You will see many "old_components" in the components field, please ignore them. 

results

You have successfully exported the urdf file. Also, you got `.stl` files in the "Desktop/test/mm_stl" repository. This will be required at the next step. The existing fusion CAD file is no more needed. You can delete it. 

The folder "Desktop/test" will be required in the next step. Move them into your ros environment.

#### In your ROS environment

Place the generated _description package directory in your own ROS workspace. "catkin_ws" is used in this example.
Then, run catkin_make in catkin_ws.

```bash
cd ~/catkin_ws/
catkin_make
source devel/setup.bash
```

Now you can see your robot in rviz. You can see it by the following command.

```bash
roslaunch (whatever your robot_name is)_description display.launch
```

rviz

If you want to simulate your robot on gazebo, just run
```bash
roslaunch (whatever your robot_name is)_description gazebo.launch
```

**Enjoy your Fusion 360 and ROS life!**

# Citation

```
@misc{toshinori2020fusion2urdf,
    author = {Toshinori Kitamura},
    title = {Fusion2URDF},
    year = {2020},
    publisher = {GitHub},
    journal = {GitHub repository},
    howpublished = {\url{https://github.com/syuntoku14/fusion2urdf}}
}
```

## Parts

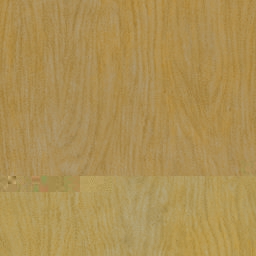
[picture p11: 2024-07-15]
ROS/ros_real_robot_v2_simulations/ros_real_robot_v2_gazebo/models/cafe_table/materials/textures/Maple.jpg

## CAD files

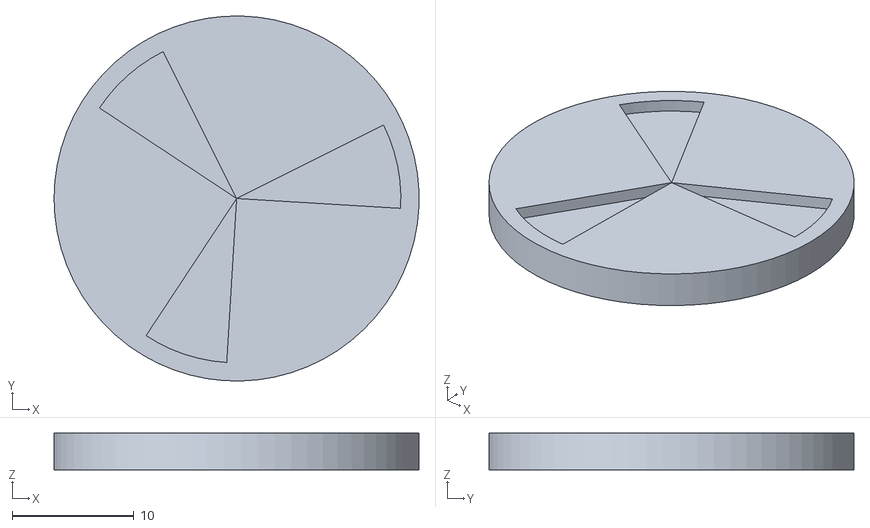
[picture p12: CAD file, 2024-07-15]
Scripts/fusion2urdf-20220426/Example/Basic_Robot_description/meshes/left_wheel_1.stl
30.0 x 30.0 x 3.00

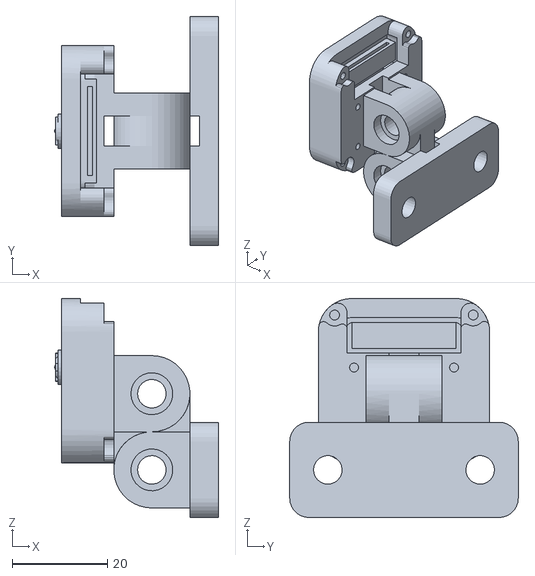
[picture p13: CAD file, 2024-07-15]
ROS/ros_real_robot_v2/ros_real_robot_v2_description/meshes/camera_rear.stl
34.4 x 48.0 x 46.0

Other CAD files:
ROS/ros_real_robot_v2/ros_real_robot_v2_description/meshes/wheel_right.stl
Scripts/fusion2urdf-20220426/Example/Basic_Robot_description/meshes/base_link.stl
ROS/ros_real_robot_v2/ros_real_robot_v2_description/meshes/rplidar.stl
ROS/ros_real_robot_v2/ros_real_robot_v2_description/meshes/bno055.stl
Scripts/fusion2urdf-20220426/Example/Basic_Robot_description/meshes/right_wheel_1.stl
ROS/ros_real_robot_v2/ros_real_robot_v2_description/meshes/caster_front.stl
ROS/ros_real_robot_v2/ros_real_robot_v2_description/meshes/base_scan.stl
ROS/ros_real_robot_v2/ros_real_robot_v2_description/meshes/camera_front.stl
ROS/ros_real_robot_v2/ros_real_robot_v2_description/meshes/caster_rear.stl
ROS/ros_real_robot_v2/ros_real_robot_v2_description/meshes/wheel_left.stl
CAD/3R2_ROS_Real_Robot_v2_v1.f3z
CAD/ros_real_robot_v2_v1.f3z
Scripts/fusion2urdf-20220426/Example/Basic_Robot.f3d

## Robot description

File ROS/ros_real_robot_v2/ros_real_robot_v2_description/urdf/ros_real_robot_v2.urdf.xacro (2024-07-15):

<?xml version="1.0" ?>
<robot name="ros_real_robot_v2" xmlns:xacro="http://www.ros.org/wiki/xacro">

<xacro:include filename="$(find ros_real_robot_v2_description)/urdf/materials.urdf.xacro" />
<xacro:include filename="$(find ros_real_robot_v2_description)/urdf/ros_real_robot_v2.urdf.trans" />

<xacro:include filename="$(find ros_real_robot_v2_description)/urdf/materials.gazebo.xacro" />
<xacro:include filename="$(find ros_real_robot_v2_description)/urdf/physics.gazebo.xacro" />
<xacro:include filename="$(find ros_real_robot_v2_description)/urdf/plugins.gazebo.xacro" />

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
<link name="base_footprint" />

<link name="base_link">
    <inertial>
        <origin xyz="0.02369358148249585 -0.007174623713539957 0.14713024435724303" rpy="0 0 0" />
        <mass value="9.059636339054258" />
        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
    </inertial>
    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
</link>

<link name="wheel_left">
    <inertial>
        <origin xyz="1.3111277514863686e-05 -0.04220393837307815 -4.2345787200026574e-05" rpy="0 0 0" />
        <mass value="1.4971511982699452" />
        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
    </inertial>
    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
</link>

<link name="wheel_right">
    <inertial>
        <origin xyz="1.3111277517311283e-05 0.04220393837307809 4.234578719894411e-05" rpy="0 0 0" />
        <mass value="1.4971511982699452" />
        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
    </inertial>
    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
</link>

<link name="caster_front">
    <inertial>
        <origin xyz="0.047646195189250826 2.718813883808386e-05 -0.024191474131117253" rpy="0 0 0" />
        <mass value="0.28273597112312876" />
        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
    </inertial>
    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
</link>

<link name="caster_rear">
    <inertial>
        <origin xyz="-0.047646195189256516 -2.7188138840351194e-05 -0.024191474131117288" rpy="0 0 0" />
        <mass value="0.28273597112312876" />
        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
    </inertial>
    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
</link>

<link name="rplidar">
    <inertial>
        <origin xyz="0.032660756880946856 -0.00022121256067097531 0.003022354511876796" rpy="0 0 0" />
        <mass value="0.5776298875699506" />
        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
    </inertial>
    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
</link>

<link name="base_scan">
    <inertial>
        <origin xyz="-0.0064741402882804305 -0.0015227092989958774 0.005323024531278475" rpy="0 0 0" />
        <mass value="0.06888185795084692" />
        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
    </inertial>
    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
</link>

<link name="camera_front">
    <inertial>
        <origin xyz="0.025691004587218777 -9.152980606665397e-06 -0.030088097026009147" rpy="0 0 0" />
        <mass value="0.25794552013170174" />
        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
    </inertial>
    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
</link>

<link name="camera_front_lens" />

<link name="camera_rear">
    <inertial>
        <origin xyz="-0.017268730716796715 -0.00010880033823036161 0.019460585139726982" rpy="0 0 0" />
        <mass value="0.11555072453846764" />
        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
    </inertial>
    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
</link>

<link name="camera_rear_lens" />

<link name="bno055">
    <inertial>
        <origin xyz="0.01418901129170208 -0.050015254782258524 0.012898924176121318" rpy="0 0 0" />
        <mass value="0.3009844640448875" />
        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
    </inertial>
    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
</link>

<link name="imu_link" />

<joint name="base_footprint__base_link" type="fixed">
    <parent link="base_footprint" />
    <child link="base_link" />
</joint>

<joint name="wheel_left__base_link" type="continuous">
    <origin xyz="0.0 0.211 0.1" rpy="0 0 0" />
    <parent link="base_link" />
    <child link="wheel_left" />
    <axis xyz="0.0 1.0 0.0" />
</joint>

<joint name="wheel_right__base_link" type="continuous">
    <origin xyz="0.0 -0.211 0.1" rpy="0 0 0" />
    <parent link="base_link" />
    <child link="wheel_right" />
    <axis xyz="0.0 1.0 0.0" />
</joint>

<joint name="caster_front__base_link" type="fixed">
    <origin xyz="0.1105 0.0 0.084" rpy="0 0 0" />
    <parent link="base_link" />
    <child link="caster_front" />
</joint>

<joint name="caster_rear__base_link" type="fixed">
    <origin xyz="-0.1105 0.0 0.084" rpy="0 0 0" />
    <parent link="base_link" />
    <child link="caster_rear" />
</joint>

<joint name="rplidar__base_link" type="fixed">
    <origin xyz="0.03 0.0 0.23858" rpy="0 0 0" />
    <parent link="base_link" />
    <child link="rplidar" />
</joint>

<joint name="base_scan__rplidar" type="fixed">
    <origin xyz="0.041229 0.0 0.0313" rpy="0 0 0" />
    <parent link="rplidar" />
    <child link="base_scan" />
</joint>

<joint name="camera_front__base_link" type="fixed">
    <origin xyz="0.0295 0.0 0.224" rpy="0 0 0" />
    <parent link="base_link" />
    <child link="camera_front" />
</joint>

<joint name="camera_front_lens__camera_front" type="fixed">
    <origin xyz="0.0671 -0.0 -0.034" rpy="0 0 0" />
    <parent link="camera_front" />
    <child link="camera_front_lens" />
</joint>

<joint name="camera_rear__base_link" type="fixed">
    <origin xyz="-0.15 0.0 0.0845" rpy="0 0 0" />
    <parent link="base_link" />
    <child link="camera_rear" />
</joint>

<joint name="camera_rear_lens__camera_rear" type="fixed">
    <origin xyz="-0.0342 0.0 0.03105" rpy="0 0 -3.141592" />
    <parent link="camera_rear" />
    <child link="camera_rear_lens" />
</joint>

<joint name="bno055__base_link" type="fixed">
    <origin xyz="0.042 0.06 0.094" rpy="0 0 0" />
    <parent link="base_link" />
    <child link="bno055" />
</joint>

<joint name="imu_link__bno055" type="fixed">
    <origin xyz="0.016515 -0.060077 0.022583" rpy="0 0 0" />
    <parent link="bno055" />
    <child link="imu_link" />
</joint>

</robot>

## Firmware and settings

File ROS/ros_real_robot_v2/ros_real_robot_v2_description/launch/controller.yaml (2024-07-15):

ros_real_robot_v2_controller:
    # Publish all joint states -----------------------------------
    joint_state_controller:
        type: joint_state_controller/JointStateController
        publish_rate: 50

    # Position Controllers --------------------------------------
    wheel_left__base_link_position_controller:
        type: effort_controllers/JointPositionController
        joint: wheel_left__base_link
        pid: {p: 100.0, i: 0.01, d: 10.0}
    wheel_right__base_link_position_controller:
        type: effort_controllers/JointPositionController
        joint: wheel_right__base_link
        pid: {p: 100.0, i: 0.01, d: 10.0}

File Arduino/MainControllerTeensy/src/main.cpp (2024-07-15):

//NOTE Check README.md for wheel reduction calculations

// Serial communication between ODrive and Teensy (Serial1)
// Teensy 4.1 - ODrive 3.6
// GND        - GND      (J3)
// GPIO0 RX   - GPIO1 TX (J3)
// GPIO1 TX   - GPIO2 RX (J3)

// Push button 1 - for initialising ODrive
// Teensy 4.1 - PBS-33B Tactile Push Button
// GND        - Pin 1
// GPIO5      - Pin 2

// #define LED_BUILTIN 13

#ifndef BUTTON1_PIN
#define BUTTON1_PIN 5
#endif

#include <ODriveArduino.h>

#include "ros.h"
#include "geometry_msgs/Twist.h"
#include <ros/time.h>
#include <tf/tf.h>
#include <tf/transform_broadcaster.h>
#include <nav_msgs/Odometry.h>
#include <geometry_msgs/Vector3.h>

ODriveArduino odrive1(Serial1);

//TODO Make it consistent with http://wiki.ros.org/navigation/Tutorials/RobotSetup/Odom and keep same units (meters over millimeters)

ros::NodeHandle nh;
geometry_msgs::TransformStamped t;
nav_msgs::Odometry odom_msg;
ros::Publisher odom_pub("odom", &odom_msg);
tf::TransformBroadcaster broadcaster;

// ODrive Motor Axis configuration
int MOTOR_LEFT  = 1;
int MOTOR_RIGHT = 0;
int MOTOR_LEFT_SIGN  = -1;
int MOTOR_RIGHT_SIGN =  1;

// tf variables to be broadcast
double x = 0;
double y = 0;
double theta = 0;
double angularZ = 0;

char base_footprint[] = "base_footprint";
char odom[] = "odom";

// cmd_vel variables to be received to drive with
double demandx;
double demandz;

// timers for the sub-main loop
unsigned long currentMillis;
unsigned long previousMillis = 0; // set up timers
unsigned short int loopTime = 78; // 12.8 Hz, because /scan has 12.725 Hz (loopTime was 20 <=> 50 Hz)
double dt; // time since last execution in seconds

// ODrive init stuff
int button1Value;
int requested_state;

// output variables to drive the ODrive
double demandx_turns;
double demandz_turns;

// positions read from the ODrive
double posLeft;
double posRight;

// variables to work out the difference on each cycle
double posLeft_old;
double posRight_old;
double posLeft_diff;
double posRight_diff;
double posLeft_mm_diff;
double posRight_mm_diff;
double pos_average_mm_diff;
double pos_average_diff; // in m

// ** ROS callback & subscriber **
void velCallback(const geometry_msgs::Twist& vel)
{
     demandx = vel.linear.x;
     demandz = vel.angular.z;
}
ros::Subscriber<geometry_msgs::Twist> sub("cmd_vel" , velCallback);


void ODriveInit()
{
    //Serial1 << "w axis" << axis << ".controller.config.vel_limit " << 60000.0f << '\n';
    //Serial1 << "w axis" << axis << ".motor.config.current_lim " << 20.0f << '\n';
    //Serial1 << "w axis" << axis << ".motor.config.calibration_current " << 10.0f << '\n';
    // *** current limit and other parameers are set on the ODrive using the Odrive tool as above. ***


    // axis 1 = left motor
    //NOTE I commented out the following 2 commands as I pre-configured the motors in the odrivetool
    // requested_state = ODriveArduino::AXIS_STATE_MOTOR_CALIBRATION;
    // odrive1.run_state(MOTOR_LEFT, requested_state, true);

    // requested_state = ODriveArduino::AXIS_STATE_ENCODER_OFFSET_CALIBRATION;
    // odrive1.run_state(MOTOR_LEFT, requested_state, true);

    requested_state = ODriveArduino::AXIS_STATE_CLOSED_LOOP_CONTROL;
    odrive1.run_state(MOTOR_LEFT, requested_state, false); // don't wait


    // axis 0 = right motor
    //NOTE I commented out the following 2 commands as I pre-configured the motors in the odrivetool
    // requested_state = ODriveArduino::AXIS_STATE_MOTOR_CALIBRATION;
    // odrive1.run_state(MOTOR_RIGHT, requested_state, true);

    // requested_state = ODriveArduino::AXIS_STATE_ENCODER_OFFSET_CALIBRATION;
    // odrive1.run_state(MOTOR_RIGHT, requested_state, true);

    requested_state = ODriveArduino::AXIS_STATE_CLOSED_LOOP_CONTROL;
    odrive1.run_state(MOTOR_RIGHT, requested_state, false); // don't wait
}


void setup()
{
    pinMode(LED_BUILTIN, OUTPUT);
    pinMode(BUTTON1_PIN, INPUT_PULLUP); // ODrive init switch

    nh.getHardware()->setBaud(115200);
    nh.initNode();            // init ROS
    nh.subscribe(sub);        // subscribe to cmd_vel
    nh.advertise(odom_pub);
    broadcaster.init(nh);     // set up broadcaster

    Serial1.begin(115200);    // ODrive
    // Serial6.begin(115200);    // debug port using a USB-serial adapter (Serial-zero is in use by ros_serial)
}

void loop()
{
    nh.spinOnce(); // make sure we listen for ROS messages and activate the callback if there is one

    currentMillis = millis();
    if (currentMillis - previousMillis < loopTime) {  // run a loop every 10ms
        return;
    }
    dt = (currentMillis - previousMillis) / 1000.0;   // time since last execution in seconds
    previousMillis = currentMillis;                   // reset the clock to time it


    // -------------------------------- Initialise ODrive (set both axis in closed loop control)
    button1Value = digitalRead(BUTTON1_PIN);
    if (button1Value == LOW) {
        digitalWrite(LED_BUILTIN, HIGH);
        ODriveInit();
        digitalWrite(LED_BUILTIN, LOW);
    }


    // -------------------------------- Calculate velocities to be sent to ODrive, in order to drive the wheels
    // (James) forward0 = demandx * 83466; // convert m/s into counts/s
    // (James) forward1 = demandx * 83466; // convert m/s into counts/s
    demandx_turns = demandx * 10.185916;   // convert m/s into turns/s
    // (1 * 1000 / 628.318530 * 6.4 = 10.185916)

    // (James) turn0 = demandz * 15091;    // convert rads/s into counts/s
    // (James) turn1 = demandz * 15091;    // convert rads/s into counts/s
    demandz_turns = demandz * 1.762163;    // convert rads/s into turns/s
    // (1 * (346 * 3.141592 / 2) / 628.318530 * 6.4 / 3.141592 = 1.762163)
    // (used to be 1.833464 based on 3d model measurements)

    //NOTE One motor-encoder pair (left) is mounted facing the other way
    odrive1.SetVelocity(MOTOR_LEFT,  demandx_turns * MOTOR_LEFT_SIGN  + demandz_turns);
    odrive1.SetVelocity(MOTOR_RIGHT, demandx_turns * MOTOR_RIGHT_SIGN + demandz_turns);



    // -------------------------------- Get positions from Odrive, in order to compute /odom and /tf messages
    posLeft  = odrive1.GetPosition(MOTOR_LEFT)  * MOTOR_LEFT_SIGN;
    posRight = odrive1.GetPosition(MOTOR_RIGHT) * MOTOR_RIGHT_SIGN;

    // work out the difference on each loop, and bookmark the old value
    posLeft_diff = posLeft - posLeft_old;
    posLeft_old = posLeft;
    posRight_diff = posRight - posRight_old;
    posRight_old = posRight;

    // calc mm from encoder counts
    // (James) pos0_mm_diff = pos0_diff / 83.44;
    // (James) pos1_mm_diff = pos1_diff / 83.44;

    // calc mm from turns
    posLeft_mm_diff  = posLeft_diff  / 0.010185;
    posRight_mm_diff = posRight_diff / 0.010185;
    // (6.4 / 628.318530 = 0.010185)
    // (used to be 0.010185 based on 3d model measurements)

    // calc distance travelled based on average of both wheels
    pos_average_mm_diff = (posLeft_mm_diff + posRight_mm_diff) / 2; // difference in each cycle
    pos_average_diff = pos_average_mm_diff / 1000; // convert mm to m

    // calc angle or rotation to broadcast with tf
    //NOTE It's okay to use mm here as both parts are in the same unit
    angularZ = (posRight_mm_diff - posLeft_mm_diff) / 346; //NOTE The distance between wheels

    //NOTE Some sources recommend adding '* dt', but it won't work well for us (the scan readings would be delayed)
    //NOTE One source recommends adding '/ 2', but it won't work well for us (the scan readings would be delayed)
    //NOTE One source recommenda adding 'asin(', but it won't work at all for us (invalid quaternion in the transform)
    theta += angularZ;

    // Keep theta between -PI and PI
    //NOTE I tried multiple variations for the next area though it doens't seem to help with the scan readings being delayed
    if (theta > PI) {
        theta -= TWO_PI;
    }
    if (theta < -PI) {
        theta += TWO_PI;
    }

    x += pos_average_diff * cos(theta);
    y += pos_average_diff * sin(theta);


    // *** broadcast odom->base_footprint transform with tf ***
    geometry_msgs::TransformStamped t;
    t.header.stamp = nh.now();
    t.header.frame_id = odom;
    t.child_frame_id = base_footprint;

    t.transform.translation.x = x;
    t.transform.translation.y = y;
    t.transform.translation.z = 0;

    t.transform.rotation = tf::createQuaternionFromYaw(theta);

    broadcaster.sendTransform(t);


    // *** broadcast odom message ***
    nav_msgs::Odometry odom_msg;
    odom_msg.header.stamp = nh.now();
    odom_msg.header.frame_id = odom;
    odom_msg.child_frame_id = base_footprint;

    odom_msg.pose.pose.position.x = x;
    odom_msg.pose.pose.position.y = y;
    odom_msg.pose.pose.position.z = 0.0;
    odom_msg.pose.pose.orientation = tf::createQuaternionFromYaw(theta);

    odom_msg.twist.twist.linear.x = pos_average_diff / dt;         // should match forward linear velocity
    odom_msg.twist.twist.linear.y = 0.0;                           // robot does not move sideways
    odom_msg.twist.twist.angular.z = angularZ / dt;                // should match angular velocity

    //NOTE Adding covariance according to https://automaticaddison.com/how-to-publish-wheel-odometry-information-over-ros/
    //NOTE If we don't manually set these, the whole matrix is filled with 0s
    //NOTE This is needed for <node pkg="robot_pose_ekf" type="robot_pose_ekf" name="robot_pose_ekf">
    //NOTE This helps with <node pkg="robot_localization" type="ekf_localization_node" name="ekf_localization" clear_params="true">
    //TODO Investigate how to do it properly
    for (int i = 0; i < 36; i++) {
        if (i == 0 || i == 7 || i == 14) {
            odom_msg.pose.covariance[i] = .01;
        } else if (i == 21 || i == 28 || i== 35) {
            odom_msg.pose.covariance[i] += 0.1;
        } else {
            odom_msg.pose.covariance[i] = 0;
        }
    }

    //NOTE For debugging
    //odom_msg.pose.pose.position.x = demandx; // vel.linear.x
    //odom_msg.pose.pose.position.z = demandz; // vel.angular.z
    //odom_msg.pose.pose.orientation.x = (demandx_turns + demandz_turns) * MOTOR_RIGHT_SIGN; // setVelocity(0)
    //odom_msg.pose.pose.orientation.y = (demandx_turns + demandz_turns) * MOTOR_LEFT_SIGN;  // setVelocity(1)
    //odom_msg.twist.twist.linear.x = posLeft; // getPosition(1) * -1
    //odom_msg.twist.twist.linear.y = posRight; // getPosition(0)
    //odom_msg.twist.twist.angular.x = posLeft_diff; // pos0 - pos0_old
    //odom_msg.twist.twist.angular.y = posRight_diff; // pos1 - pos1_old
    //odom_msg.pose.pose.orientation.z = theta; // adding or substracting two_pi
    //odom_msg.pose.pose.orientation.w = pos_average_mm_diff; // (posLeft_mm_diff + posRight_mm_diff) / 2
    //odom_msg.twist.twist.linear.z = dt; // time since last execution in seconds

    odom_pub.publish(&odom_msg);
} // end loop

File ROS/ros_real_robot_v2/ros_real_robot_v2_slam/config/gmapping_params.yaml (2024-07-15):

map_update_interval: 2.0
maxUrange: 8.0
sigma: 0.05
kernelSize: 1
lstep: 0.05
astep: 0.05
iterations: 5
lsigma: 0.075
ogain: 3.0
lskip: 0
minimumScore: 50
srr: 0.1
srt: 0.2
str: 0.1
stt: 0.2
linearUpdate: 1.0
angularUpdate: 0.2
temporalUpdate: 0.5
resampleThreshold: 0.5
particles: 100
xmin: -10.0
ymin: -10.0
xmax: 10.0
ymax: 10.0
delta: 0.05
llsamplerange: 0.01
llsamplestep: 0.01
lasamplerange: 0.005
lasamplestep: 0.005
